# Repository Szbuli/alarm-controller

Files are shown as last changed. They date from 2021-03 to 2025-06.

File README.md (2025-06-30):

# Sensor Controller

## Main Features

- **15 configurable sensor inputs**  
- **Supported power supply:** 13.8 V nominal  
- **Home Assistant autodiscovery** via MQTT gateway
- **Input types supported:**  
  - Alarm sensors with multi-level signaling (e.g., open/tamper detection)  
  - Pulse counters (e.g., utility meters)

## Hardware

- **Microcontroller:** STM32F103R8T6  
- **Non-volatile memory:** MB85RC256V FRAM  
- **CAN Bus Transceiver:** SN65HVD230  
- **Electrical protection:**  
  - Overvoltage-protected inputs  
  - Overload protection circuitry  
- **Debug Interface:** Serial Wire Debug (SWD)

## Development Tools

- **PCB Design:** Autodesk EAGLE  
- **Firmware:** STM32CubeIDE (C via HAL / LL libraries)

## Setup
1. **Assign the device ID** via MQTT topic: `smarthome/alarm_controller/config`
2. **Configure sensor input types**
-- `1` → Alarm sensor
-- `3` → Pulse counter (normally open)
-- `4` → Pulse counter (normally closed)

## Sensor Connection & Security

To ensure reliable operation and tamper detection, each sensor input must be connected using a resistor for end-of-line (EOL) supervision.
The controller uses a voltage divider circuit to distinguish between different sensor states. The correct resistor value is essential for accurate detection:

- **Switch / Door Contact Sensors:**  
  Use a **40.2 kΩ** resistor in series with the sensor contact.  
- **Alarm Sensors:**  
  - **Normal (closed) signal:** ~40 kΩ total resistance  
  - **Alarm (open) signal:** ~140 kΩ total resistance

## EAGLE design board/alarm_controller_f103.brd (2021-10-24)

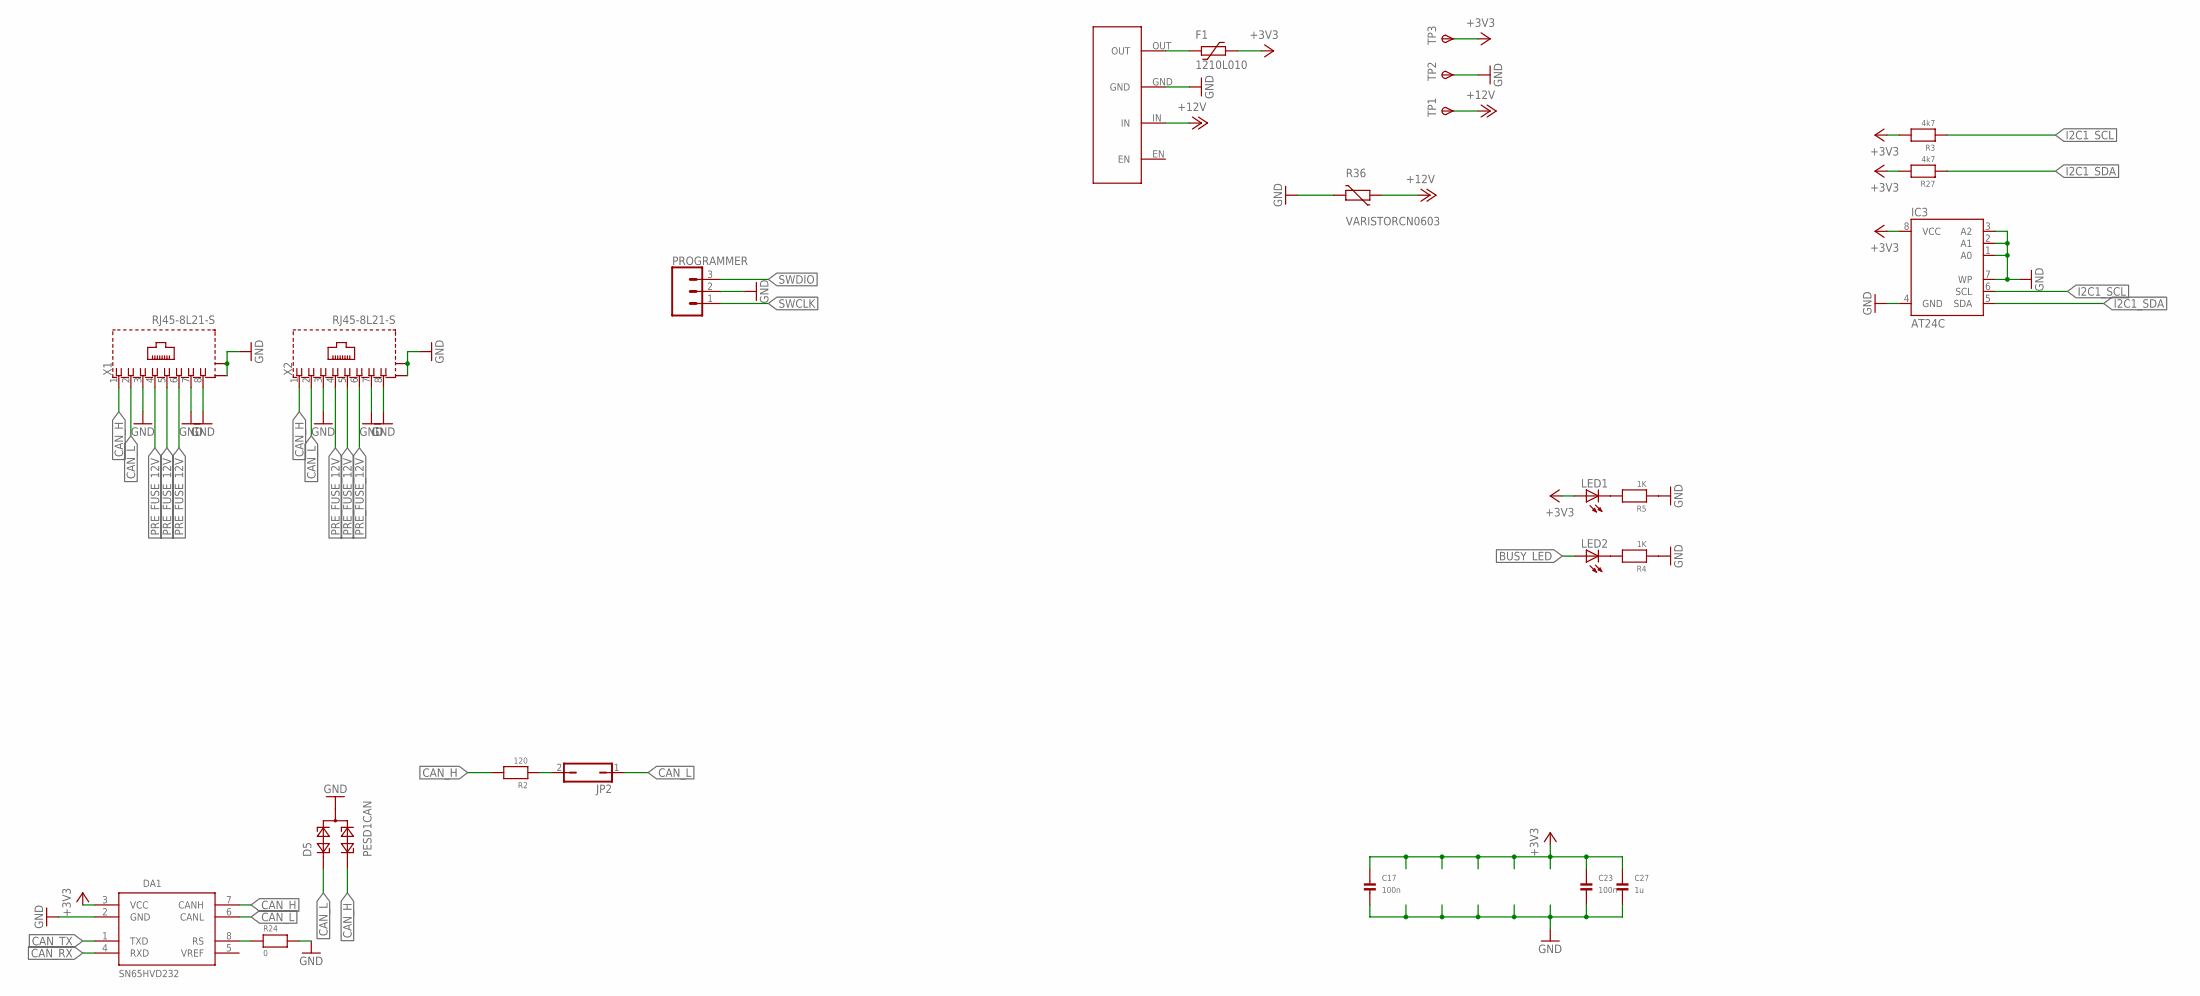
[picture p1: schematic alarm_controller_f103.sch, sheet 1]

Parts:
C17, C23: 100n; 0603
C27: 1u; 0603
D5: PESD1CAN; SOT23
DA1: SN65HVD232; SO08
F1: 1210L010; 1210L
IC3: AT24C; SOIC8
JP2: JP1Q; JP1
LED1, LED2: LEDCHIPLED_0805; CHIPLED_0805
PROGRAMMER: CONN_03LOCK; 1X03_LOCK
R2: 120; 0603
R3, R27: 4k7; 0603
R4, R5: 1K; 0603
R24: 0; 0603
R36: VARISTORCN0603; CT/CN0603
TP1, TP2, TP3: TPSTP20R; TP20R
U$4: HW-613
X1, X2: RJ45-8L21-S; RJ45-SHIELD1

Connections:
+3V3: C17.1, C23.1, C27.1, DA1.3 (VCC), F1.1, IC3.8 (VCC), LED1.A, R3.2, R27.2, TP3.TP; also elsewhere on the board
+12V: R36.1, TP1.TP, U$4.IN; also elsewhere on the board
BUSY_LED: LED2.A; also elsewhere on the board
CAN_H: D5.2, DA1.7 (CANH), R2.2, X1.1, X2.1
CAN_L: D5.1, DA1.6 (CANL), JP2.1, X1.2, X2.2
CAN_RX: DA1.4 (RXD); also elsewhere on the board
CAN_TX: DA1.1 (TXD); also elsewhere on the board
GND: C17.2, C23.2, C27.2, D5.3, DA1.2 (GND), IC3.1 (A0), IC3.2 (A1), IC3.3 (A2), IC3.4 (GND), IC3.7 (WP), PROGRAMMER.2, R4.1, R5.1, R24.2, R36.2, TP2.TP, U$4.GND, X1.3, X1.7, X1.8, X1.S1 (S), X1.S2 (S), X2.3, X2.7, X2.8, X2.S1 (S), X2.S2 (S); also elsewhere on the board
I2C1_SCL: IC3.6 (SCL), R3.1; also elsewhere on the board
I2C1_SDA: IC3.5 (SDA), R27.1; also elsewhere on the board
unnamed: F1.2, U$4.OUT
unnamed: LED1.C, R5.2
unnamed: LED2.C, R4.2
unnamed: JP2.2, R2.1
unnamed: DA1.8 (RS), R24.1
PRE_FUSE_12V: X1.4, X1.5, X1.6, X2.4, X2.5, X2.6; also elsewhere on the board
SWCLK: PROGRAMMER.1; also elsewhere on the board
SWDIO: PROGRAMMER.3; also elsewhere on the board

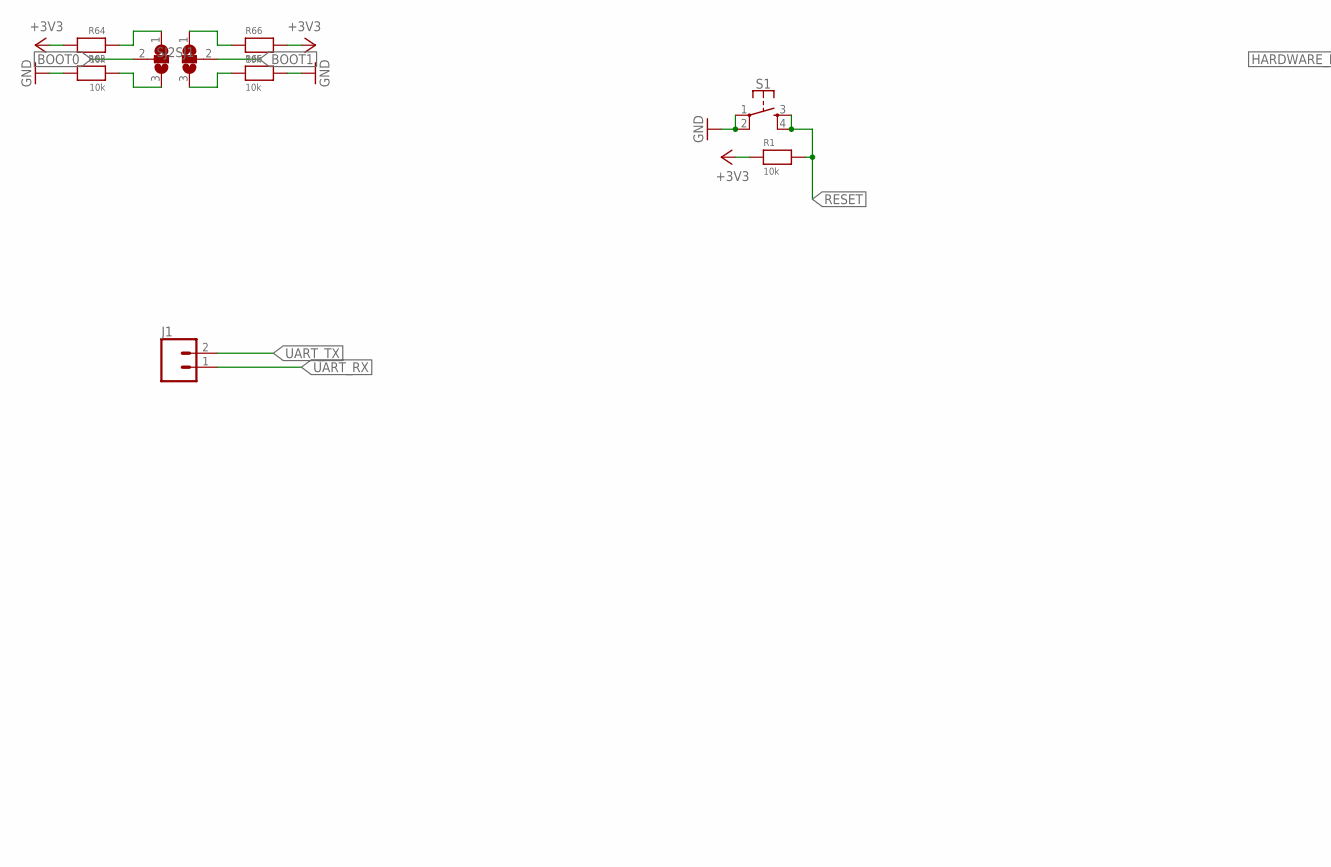
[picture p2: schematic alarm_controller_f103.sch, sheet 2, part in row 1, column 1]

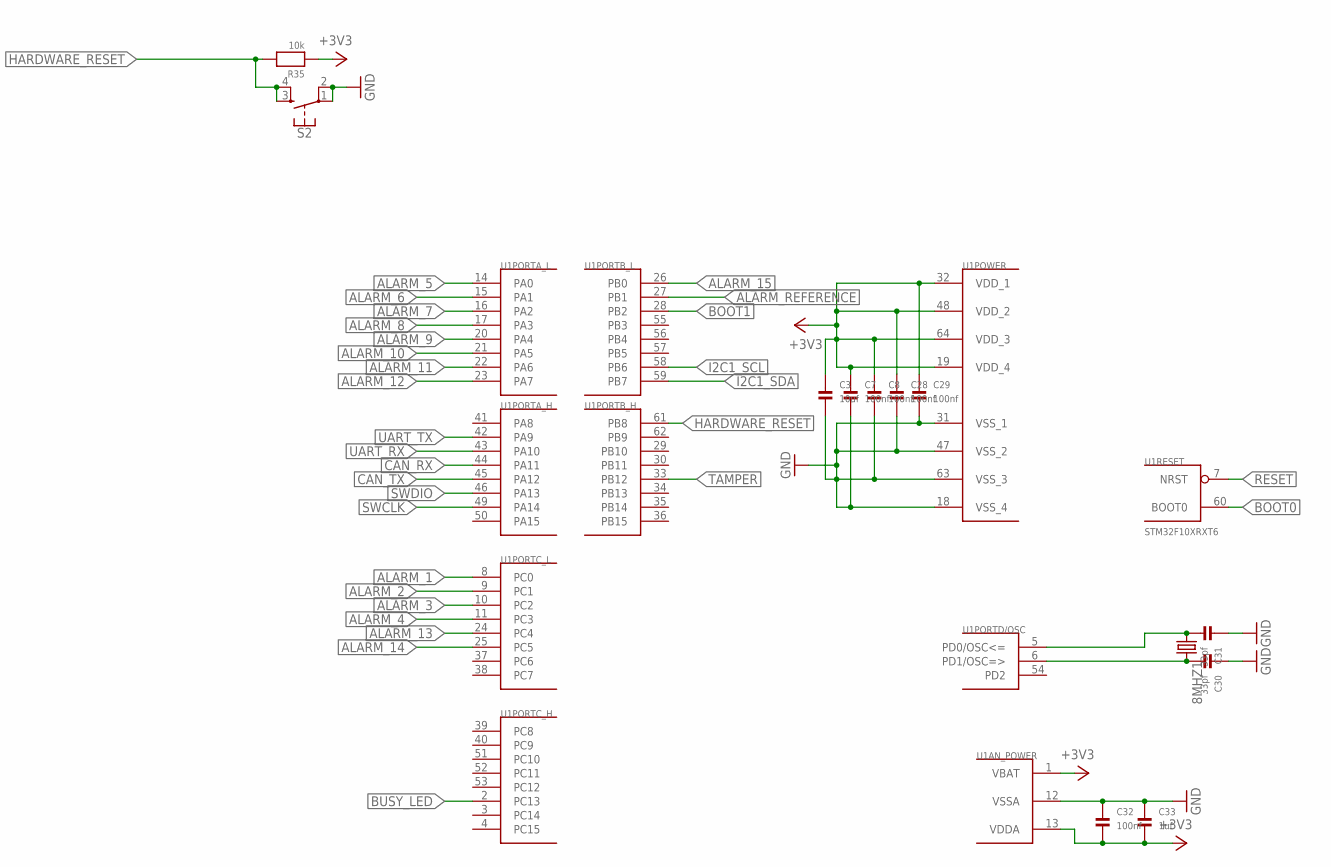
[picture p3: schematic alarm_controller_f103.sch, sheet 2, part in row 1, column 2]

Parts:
8MHZ1: CRYSTALHC49UP; HC49UP
C3: 10uf; 0805
C7, C8, C28, C29, C32: 100nf; 0603-MINI
C30, C31: 33pf; 0603
C33: 1uf; 0603-MINI
J1: CONN_02; 1X02
R1, R35, R63, R64, R65, R66: 10k; 0603
S1, S2: MOMENTARY-SWITCH-SPST-2-SMD-4.6X2.8MM; TACTILE_SWITCH_SMD_4.6X2.8MM
SJ1, SJ2: SJ2W; SJ_2
U1: STM32F10XRXT6; TQFP64

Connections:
+3V3: C3.1, C7.1, C8.1, C28.1, C29.1, C32.2, C33.2, R1.1, R35.1, R64.2, R66.2, U1.1 (VBAT), U1.13 (VDDA), U1.19 (VDD_4), U1.32 (VDD_1), U1.48 (VDD_2), U1.64 (VDD_3); also elsewhere on the board
ALARM_1: U1.8 (PC0); also elsewhere on the board
ALARM_2: U1.9 (PC1); also elsewhere on the board
ALARM_3: U1.10 (PC2); also elsewhere on the board
ALARM_4: U1.11 (PC3); also elsewhere on the board
ALARM_5: U1.14 (PA0); also elsewhere on the board
ALARM_6: U1.15 (PA1); also elsewhere on the board
ALARM_7: U1.16 (PA2); also elsewhere on the board
ALARM_8: U1.17 (PA3); also elsewhere on the board
ALARM_9: U1.20 (PA4); also elsewhere on the board
ALARM_10: U1.21 (PA5); also elsewhere on the board
ALARM_11: U1.22 (PA6); also elsewhere on the board
ALARM_12: U1.23 (PA7); also elsewhere on the board
ALARM_13: U1.24 (PC4); also elsewhere on the board
ALARM_14: U1.25 (PC5); also elsewhere on the board
ALARM_15: U1.26 (PB0); also elsewhere on the board
ALARM_REFERENCE: U1.27 (PB1); also elsewhere on the board
BOOT0: SJ1.2, U1.60 (BOOT0)
BOOT1: SJ2.2, U1.28 (PB2)
BUSY_LED: U1.2 (PC13); also elsewhere on the board
CAN_RX: U1.44 (PA11); also elsewhere on the board
CAN_TX: U1.45 (PA12); also elsewhere on the board
GND: C3.2, C7.2, C8.2, C28.2, C29.2, C30.1, C31.1, C32.1, C33.1, R63.2, R65.2, S1.1, S1.2, S2.1, S2.2, U1.12 (VSSA), U1.18 (VSS_4), U1.31 (VSS_1), U1.47 (VSS_2), U1.63 (VSS_3); also elsewhere on the board
HARDWARE_RESET: R35.2, S2.3, S2.4, U1.61 (PB8)
I2C1_SCL: U1.58 (PB6); also elsewhere on the board
I2C1_SDA: U1.59 (PB7); also elsewhere on the board
unnamed: R66.1, SJ2.1
unnamed: R64.1, SJ1.1
unnamed: R65.1, SJ2.3
unnamed: R63.1, SJ1.3
unnamed: 8MHZ1.2, C30.2, U1.6 (PD1/OSC=>)
unnamed: 8MHZ1.1, C31.2, U1.5 (PD0/OSC<=)
RESET: R1.2, S1.3, S1.4, U1.7 (NRST)
SWCLK: U1.49 (PA14); also elsewhere on the board
SWDIO: U1.46 (PA13); also elsewhere on the board
TAMPER: U1.33 (PB12); also elsewhere on the board
UART_RX: J1.1, U1.43 (PA10)
UART_TX: J1.2, U1.42 (PA9)

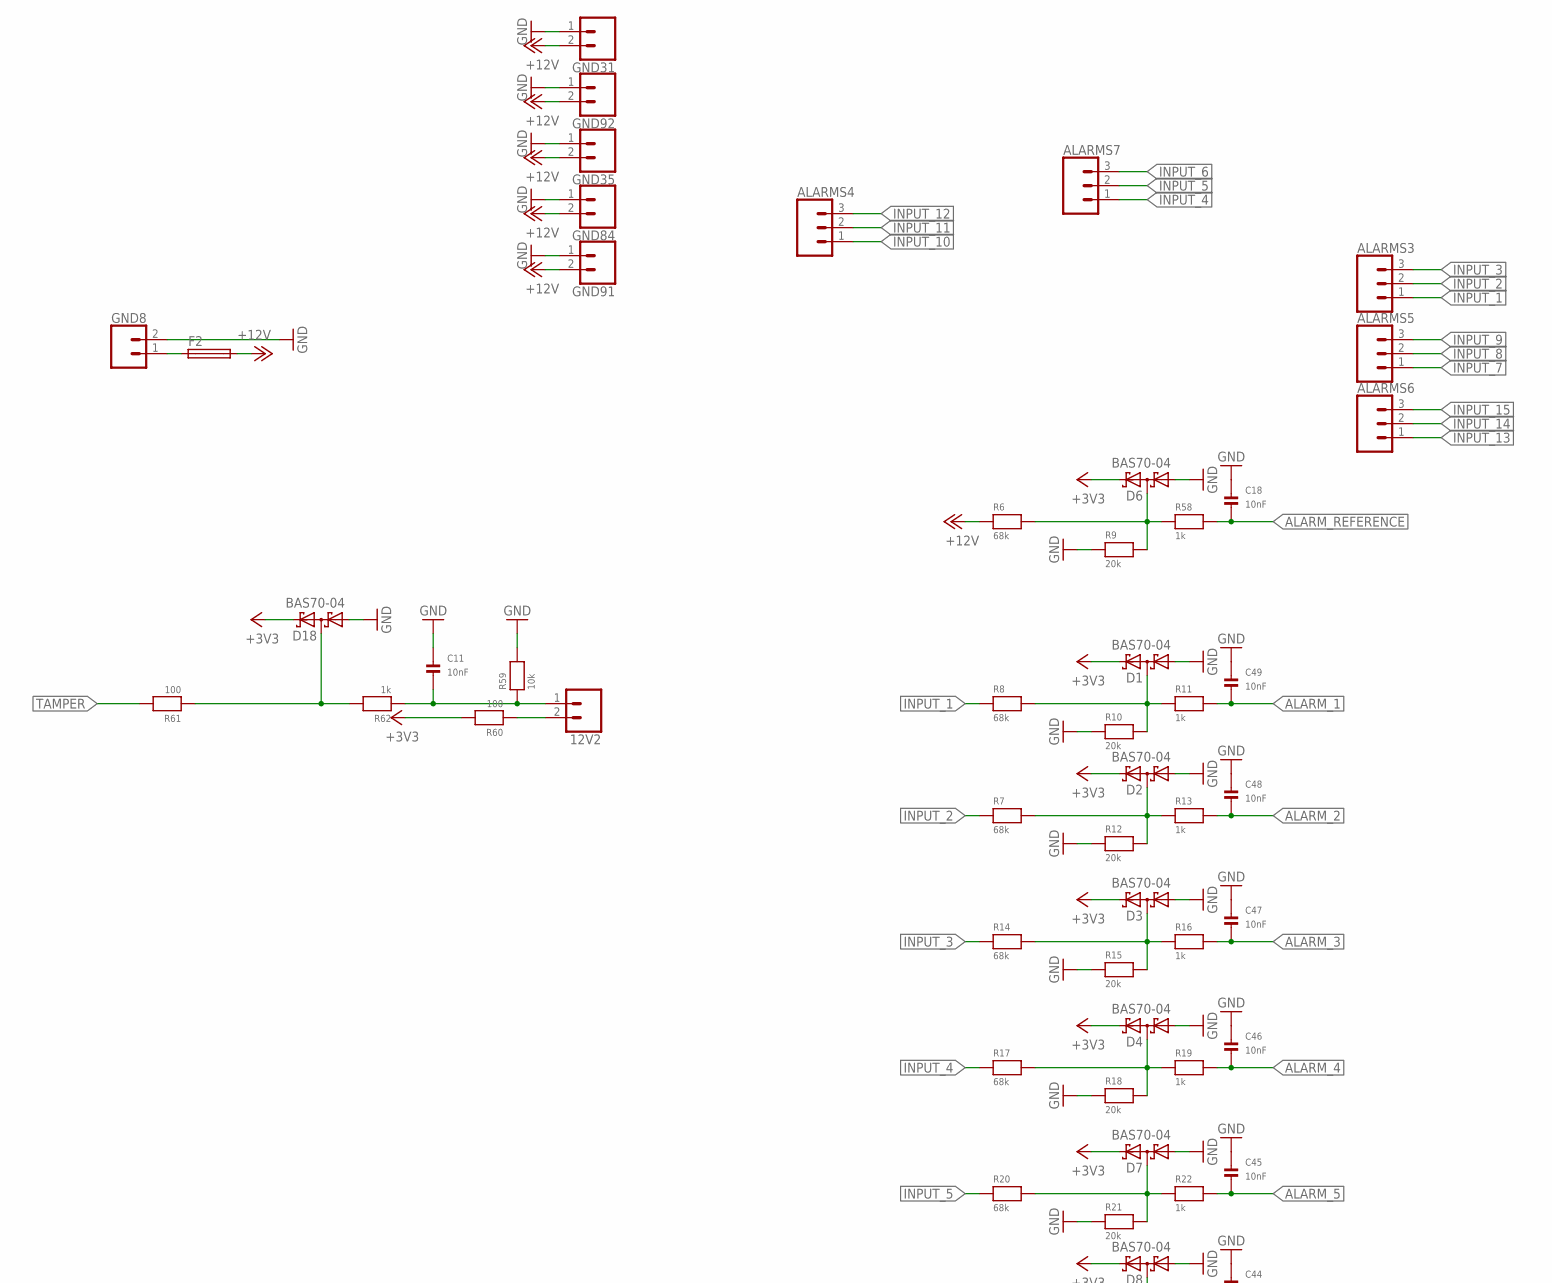
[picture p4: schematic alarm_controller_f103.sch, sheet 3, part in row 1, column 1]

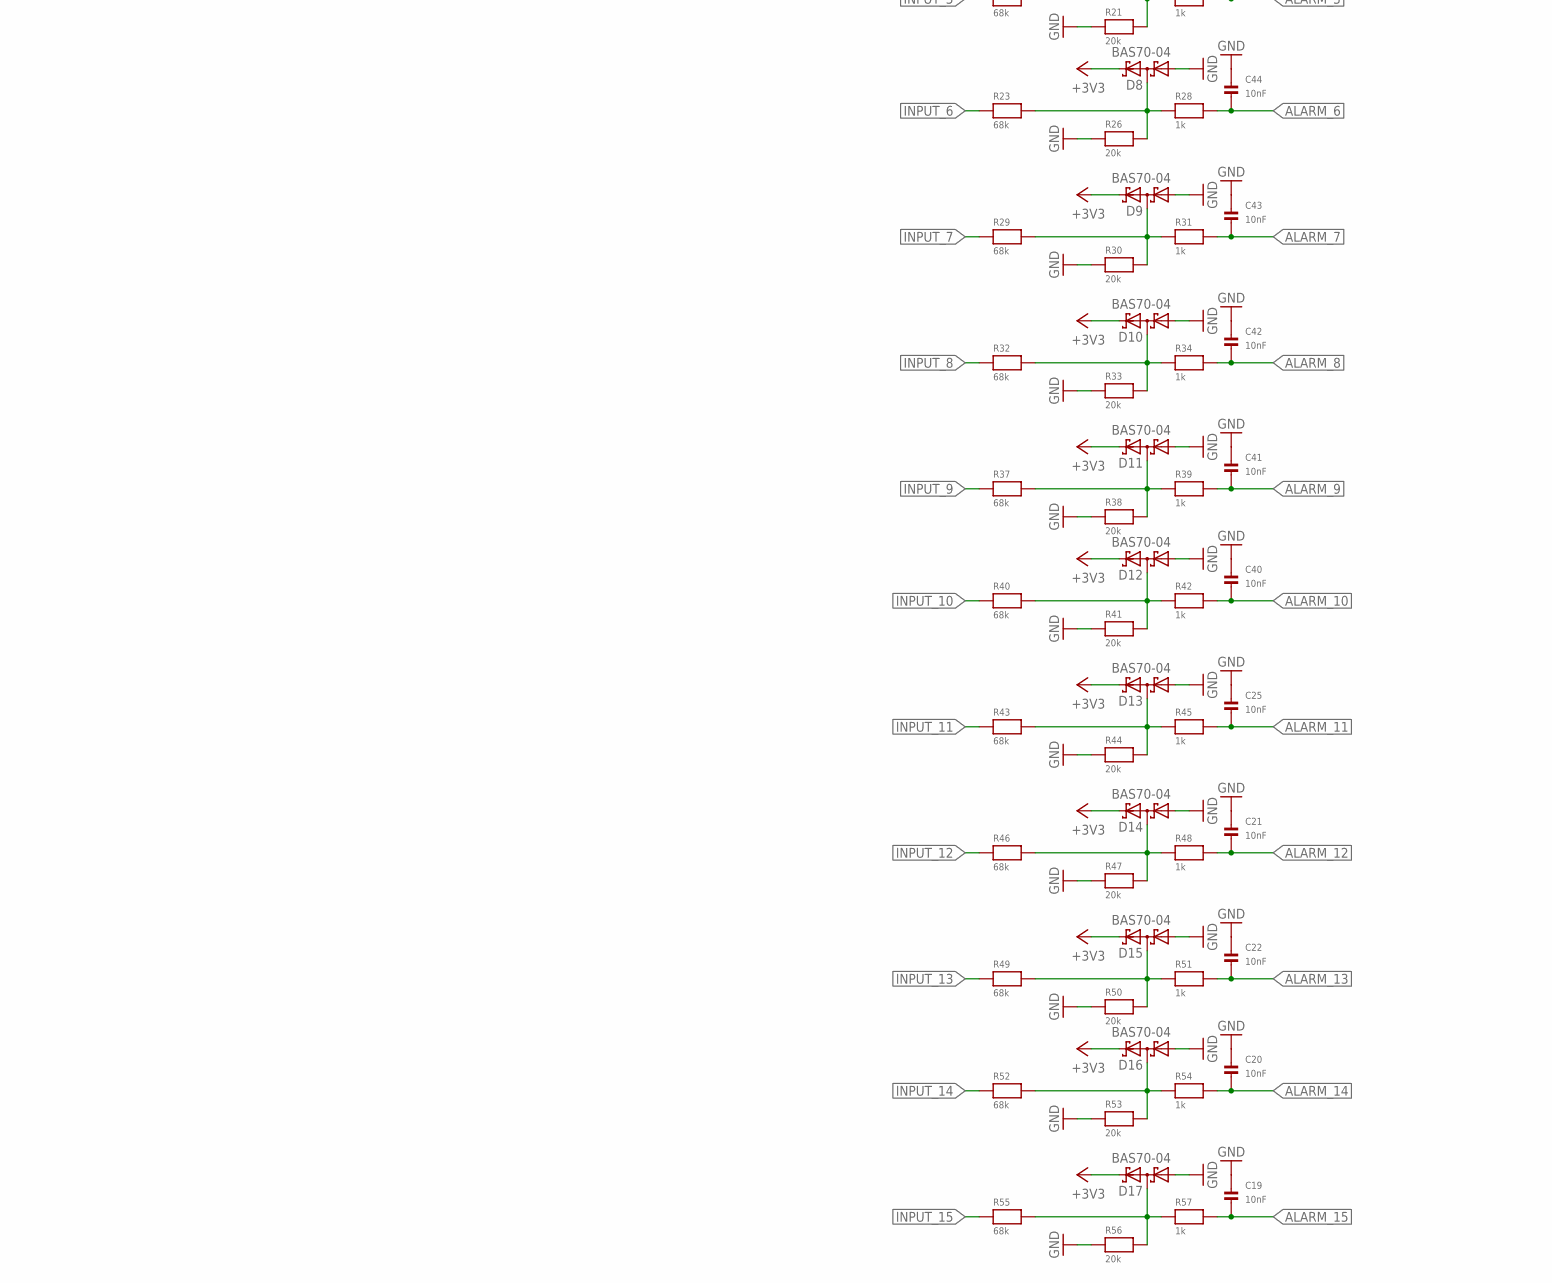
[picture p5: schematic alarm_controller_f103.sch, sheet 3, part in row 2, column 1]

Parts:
12V2: CONN_023.5MM; SCREWTERMINAL-3.5MM-2
ALARMS3, ALARMS4, ALARMS5, ALARMS6, ALARMS7: CONN_03SCREW_LOCK; SCREWTERMINAL-3.5MM-3_LOCK.007S
C11, C18, C19, C20, C21, C22, C25, C40, C41, C42, C43, C44, C45, C46, C47, C48, C49: 10nF; 0603
D1, D2, D3, D4, D6, D7, D8, D9, D10, D11, D12, D13, D14, D15, D16, D17, D18: BAS70-04; SOT23
F2: TE5
GND8: CONN_025MM; SCREWTERMINAL-5MM-2
GND31, GND35, GND84, GND91, GND92: CONN_023.5MM; SCREWTERMINAL-3.5MM-2
R6, R7, R8, R14, R17, R20, R23, R29, R32, R37, R40, R43, R46, R49, R52, R55: 68k; 0603
R9, R10, R12, R15, R18, R21, R26, R30, R33, R38, R41, R44, R47, R50, R53, R56: 20k; 0603
R11, R13, R16, R19, R22, R28, R31, R34, R39, R42, R45, R48, R51, R54, R57, R58, R62: 1k; 0603
R59: 10k; 0603
R60, R61: 100; 0603

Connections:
12V_REFERENCE1: D2.3 (C1A2), R7.2, R12.2, R13.1
12V_REFERENCE2: D3.3 (C1A2), R14.2, R15.2, R16.1
12V_REFERENCE3: D4.3 (C1A2), R17.2, R18.2, R19.1
12V_REFERENCE4: D7.3 (C1A2), R20.2, R21.2, R22.1
12V_REFERENCE5: D8.3 (C1A2), R23.2, R26.2, R28.1
12V_REFERENCE6: D9.3 (C1A2), R29.2, R30.2, R31.1
12V_REFERENCE7: D10.3 (C1A2), R32.2, R33.2, R34.1
12V_REFERENCE8: D11.3 (C1A2), R37.2, R38.2, R39.1
12V_REFERENCE9: D12.3 (C1A2), R40.2, R41.2, R42.1
12V_REFERENCE10: D13.3 (C1A2), R43.2, R44.2, R45.1
12V_REFERENCE11: D14.3 (C1A2), R46.2, R47.2, R48.1
12V_REFERENCE12: D15.3 (C1A2), R49.2, R50.2, R51.1
12V_REFERENCE13: D16.3 (C1A2), R52.2, R53.2, R54.1
12V_REFERENCE14: D17.3 (C1A2), R55.2, R56.2, R57.1
+3V3: D1.2 (C2), D2.2 (C2), D3.2 (C2), D4.2 (C2), D6.2 (C2), D7.2 (C2), D8.2 (C2), D9.2 (C2), D10.2 (C2), D11.2 (C2), D12.2 (C2), D13.2 (C2), D14.2 (C2), D15.2 (C2), D16.2 (C2), D17.2 (C2), D18.2 (C2), R60.2; also elsewhere on the board
+12V: F2.2, GND31.2, GND35.2, GND84.2, GND91.2, GND92.2, R6.1; also elsewhere on the board
A23: D6.3 (C1A2), R6.2, R9.2, R58.1
ALARM_1: C49.2, R11.2; also elsewhere on the board
ALARM_2: C48.2, R13.2; also elsewhere on the board
ALARM_3: C47.2, R16.2; also elsewhere on the board
ALARM_4: C46.2, R19.2; also elsewhere on the board
ALARM_5: C45.2, R22.2; also elsewhere on the board
ALARM_6: C44.2, R28.2; also elsewhere on the board
ALARM_7: C43.2, R31.2; also elsewhere on the board
ALARM_8: C42.2, R34.2; also elsewhere on the board
ALARM_9: C41.2, R39.2; also elsewhere on the board
ALARM_10: C40.2, R42.2; also elsewhere on the board
ALARM_11: C25.2, R45.2; also elsewhere on the board
ALARM_12: C21.2, R48.2; also elsewhere on the board
ALARM_13: C22.2, R51.2; also elsewhere on the board
ALARM_14: C20.2, R54.2; also elsewhere on the board
ALARM_15: C19.2, R57.2; also elsewhere on the board
ALARM_REFERENCE: C18.2, R58.2; also elsewhere on the board
ASD: D1.3 (C1A2), R8.2, R10.2, R11.1
ASDASD: D18.3 (C1A2), R61.1, R62.2
GND: C11.1, C18.1, C19.1, C20.1, C21.1, C22.1, C25.1, C40.1, C41.1, C42.1, C43.1, C44.1, C45.1, C46.1, C47.1, C48.1, C49.1, D1.1 (A1), D2.1 (A1), D3.1 (A1), D4.1 (A1), D6.1 (A1), D7.1 (A1), D8.1 (A1), D9.1 (A1), D10.1 (A1), D11.1 (A1), D12.1 (A1), D13.1 (A1), D14.1 (A1), D15.1 (A1), D16.1 (A1), D17.1 (A1), D18.1 (A1), GND8.2, GND31.1, GND35.1, GND84.1, GND91.1, GND92.1, R9.1, R10.1, R12.1, R15.1, R18.1, R21.1, R26.1, R30.1, R33.1, R38.1, R41.1, R44.1, R47.1, R50.1, R53.1, R56.1, R59.2; also elsewhere on the board
INPUT_1: ALARMS3.1, R8.1
INPUT_2: ALARMS3.2, R7.1
INPUT_3: ALARMS3.3, R14.1
INPUT_4: ALARMS7.1, R17.1
INPUT_5: ALARMS7.2, R20.1
INPUT_6: ALARMS7.3, R23.1
INPUT_7: ALARMS5.1, R29.1
INPUT_8: ALARMS5.2, R32.1
INPUT_9: ALARMS5.3, R37.1
INPUT_10: ALARMS4.1, R40.1
INPUT_11: ALARMS4.2, R43.1
INPUT_12: ALARMS4.3, R46.1
INPUT_13: ALARMS6.1, R49.1
INPUT_14: ALARMS6.2, R52.1
INPUT_15: ALARMS6.3, R55.1
unnamed: 12V2.2, R60.1
unnamed: 12V2.1, C11.2, R59.1, R62.1
PRE_FUSE_12V: F2.1, GND8.1; also elsewhere on the board
TAMPER: R61.2; also elsewhere on the board

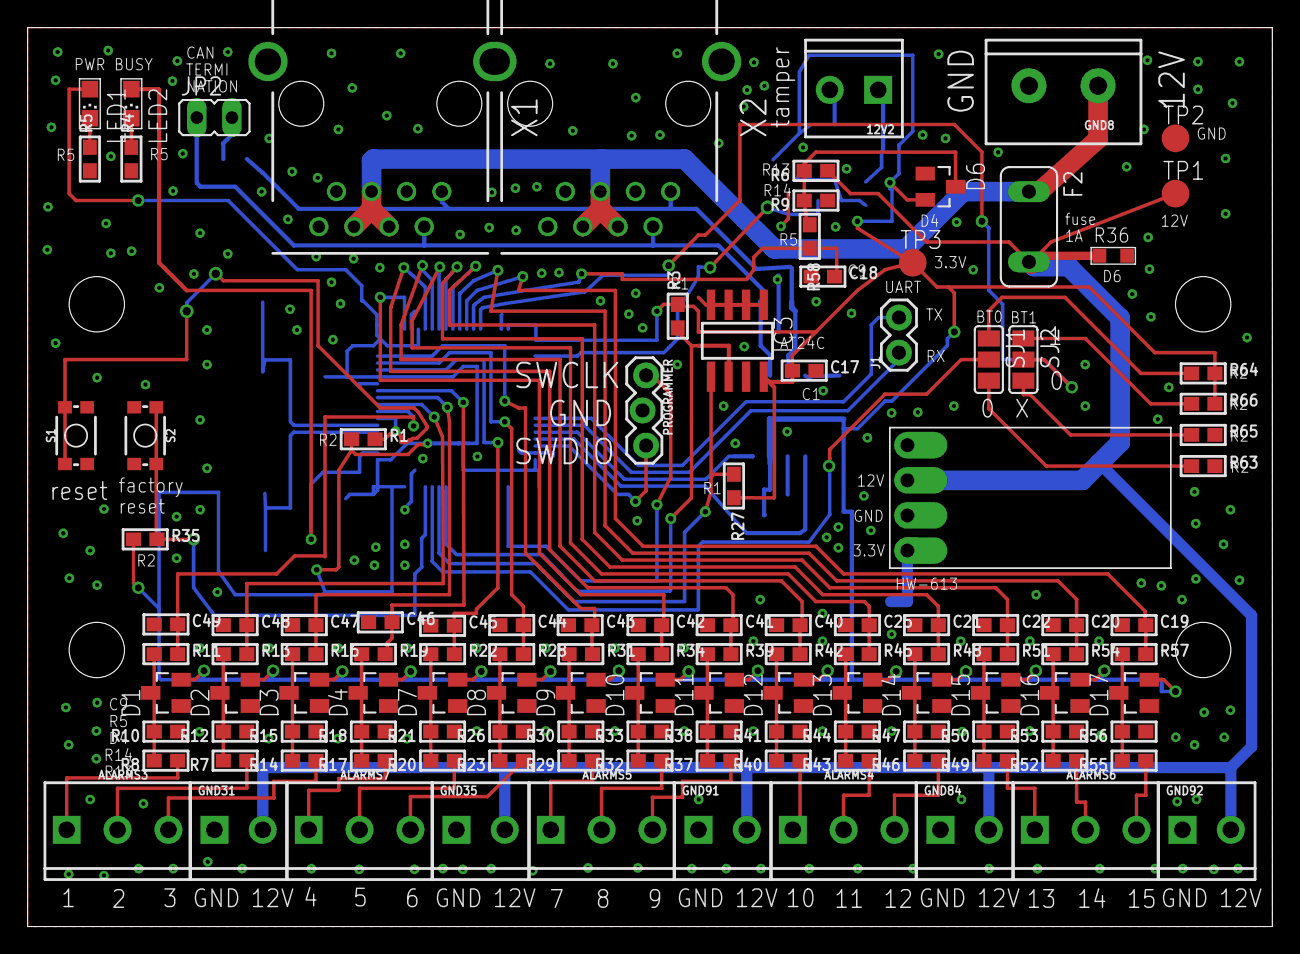
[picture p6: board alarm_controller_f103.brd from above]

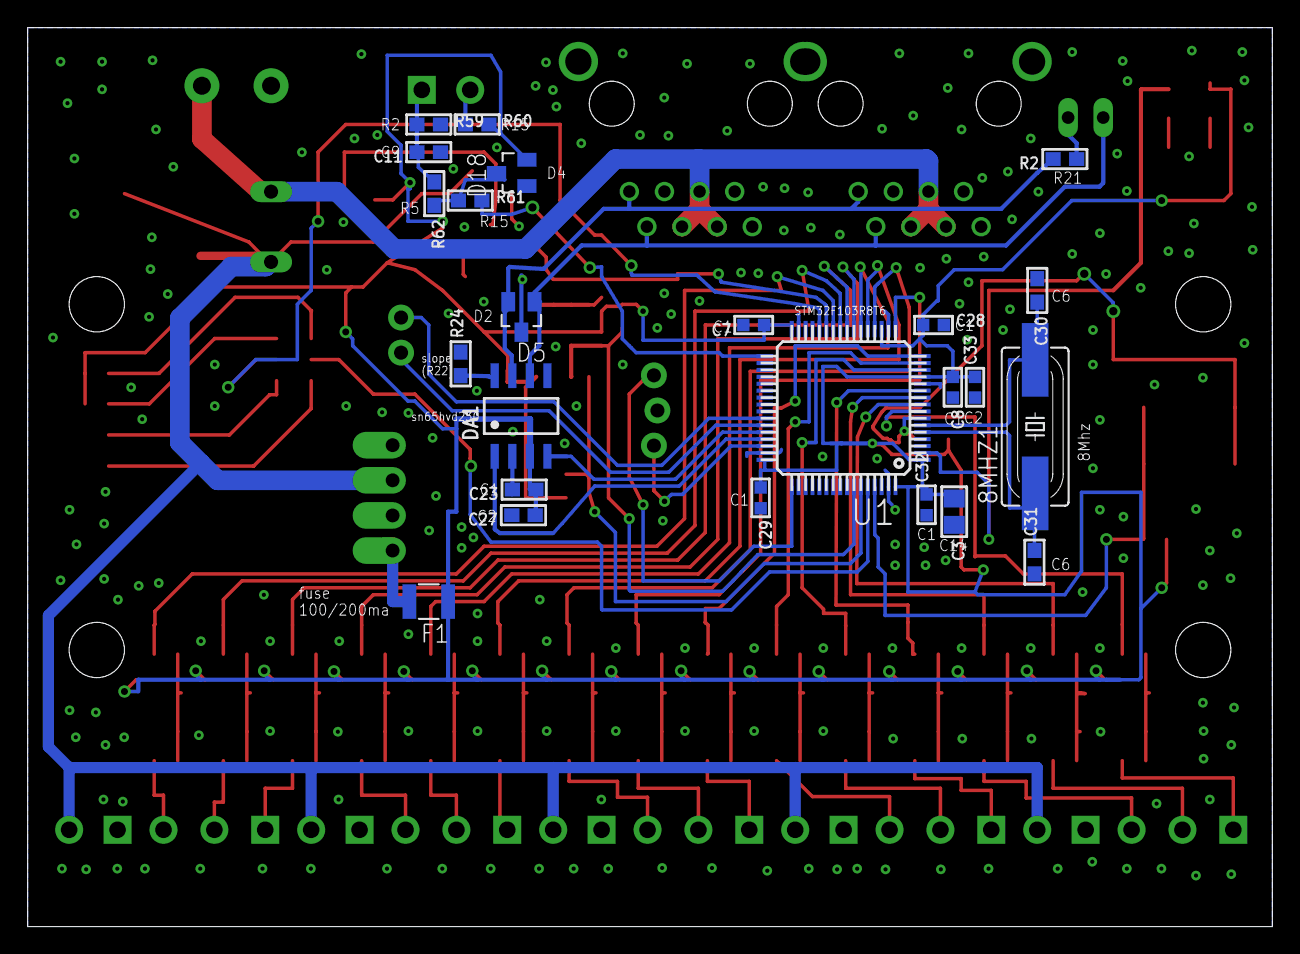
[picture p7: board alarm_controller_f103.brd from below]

Board: 2 copper layers, 90.0 x 65.0 mm, 147 parts (24 on the bottom side), 81 nets.

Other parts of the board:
U$5, U$6: C45-DIN-MOUNT-2-HOLE

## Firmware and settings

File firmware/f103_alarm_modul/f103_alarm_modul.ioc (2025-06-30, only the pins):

Mcu.UserName=STM32F103R8Tx
PA0-WKUP.GPIO_Label=ALARM_5
PA0-WKUP.Signal=ADCx_IN0
PA1.GPIO_Label=ALARM_6
PA1.Signal=ADCx_IN1
PA10.Signal=USART1_RX
PA11.Signal=CAN_RX
PA12.Signal=CAN_TX
PA13.Signal=SYS_JTMS-SWDIO
PA14.Signal=SYS_JTCK-SWCLK
PA2.GPIO_Label=ALARM_7
PA2.Signal=ADCx_IN2
PA3.GPIO_Label=ALARM_8
PA3.Signal=ADCx_IN3
PA4.GPIO_Label=ALARM_9
PA4.Signal=ADCx_IN4
PA5.GPIO_Label=ALARM_10
PA5.Signal=ADCx_IN5
PA6.GPIO_Label=ALARM_11
PA6.Signal=ADCx_IN6
PA7.GPIO_Label=ALARM_12
PA7.Signal=ADCx_IN7
PA9.Signal=USART1_TX
PB0.GPIO_Label=ALARM_15
PB0.Signal=ADCx_IN8
PB1.GPIO_Label=ALARM_12V_REFERENCE
PB1.Signal=ADCx_IN9
PB12.GPIO_Label=TAMPER
PB12.Signal=GPXTI12
PB2.GPIO_Label=BOOOOT2
PB2.Signal=GPIO_Input
PB6.Signal=I2C1_SCL
PB7.Signal=I2C1_SDA
PB8.GPIO_Label=FACTORY_RESET
PB8.Signal=GPIO_Input
PC0.GPIO_Label=ALARM_1
PC0.Signal=ADCx_IN10
PC1.GPIO_Label=ALARM_2
PC1.Signal=ADCx_IN11
PC13-TAMPER-RTC.GPIO_Label=BUSY_LED
PC13-TAMPER-RTC.Signal=GPIO_Output
PC2.GPIO_Label=ALARM_3
PC2.Signal=ADCx_IN12
PC3.GPIO_Label=ALARM_4
PC3.Signal=ADCx_IN13
PC4.GPIO_Label=ALARM_13
PC4.Signal=ADCx_IN14
PC5.GPIO_Label=ALARM_14
PC5.Signal=ADCx_IN15
PD0-OSC_IN.Signal=RCC_OSC_IN
PD1-OSC_OUT.Signal=RCC_OSC_OUT

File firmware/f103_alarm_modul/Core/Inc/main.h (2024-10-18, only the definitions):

#define BUSY_LED_Pin GPIO_PIN_13
#define BUSY_LED_GPIO_Port GPIOC
#define ALARM_1_Pin GPIO_PIN_0
#define ALARM_1_GPIO_Port GPIOC
#define ALARM_2_Pin GPIO_PIN_1
#define ALARM_2_GPIO_Port GPIOC
#define ALARM_3_Pin GPIO_PIN_2
#define ALARM_3_GPIO_Port GPIOC
#define ALARM_4_Pin GPIO_PIN_3
#define ALARM_4_GPIO_Port GPIOC
#define ALARM_5_Pin GPIO_PIN_0
#define ALARM_5_GPIO_Port GPIOA
#define ALARM_6_Pin GPIO_PIN_1
#define ALARM_6_GPIO_Port GPIOA
#define ALARM_7_Pin GPIO_PIN_2
#define ALARM_7_GPIO_Port GPIOA
#define ALARM_8_Pin GPIO_PIN_3
#define ALARM_8_GPIO_Port GPIOA
#define ALARM_9_Pin GPIO_PIN_4
#define ALARM_9_GPIO_Port GPIOA
#define ALARM_10_Pin GPIO_PIN_5
#define ALARM_10_GPIO_Port GPIOA
#define ALARM_11_Pin GPIO_PIN_6
#define ALARM_11_GPIO_Port GPIOA
#define ALARM_12_Pin GPIO_PIN_7
#define ALARM_12_GPIO_Port GPIOA
#define ALARM_13_Pin GPIO_PIN_4
#define ALARM_13_GPIO_Port GPIOC
#define ALARM_14_Pin GPIO_PIN_5
#define ALARM_14_GPIO_Port GPIOC
#define ALARM_15_Pin GPIO_PIN_0
#define ALARM_15_GPIO_Port GPIOB
#define ALARM_12V_REFERENCE_Pin GPIO_PIN_1
#define ALARM_12V_REFERENCE_GPIO_Port GPIOB
#define BOOOOT2_Pin GPIO_PIN_2
#define BOOOOT2_GPIO_Port GPIOB
#define TAMPER_Pin GPIO_PIN_12
#define TAMPER_GPIO_Port GPIOB
#define FACTORY_RESET_Pin GPIO_PIN_8
#define FACTORY_RESET_GPIO_Port GPIOB

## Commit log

2020-04-21 add board
    [alarm_controller.brd, alarm_controller.sch]
2020-05-01 init fw
    [f4_vet6_alarm_modul.cfg]
2020-05-02 change to premade power supply
    [alarm_controller.brd, alarm_controller.sch]
2020-05-03 change mounting to lib version
    [alarm_controller.brd]
2020-05-08 board - minor adjustments
    [alarm_controller.brd]
2020-05-08 update logo
    [alarm_controller.brd]
2020-05-08 add reset button
    [alarm_controller.brd, alarm_controller.sch]
2020-05-09 fix tamper
    [alarm_controller.brd, alarm_controller.sch]
2020-05-10 add support for hardware factory reset
    [f4_vet6_alarm_modul.ioc, home_config.c, home_config.h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]
2020-05-10 update uart logging
2020-06-11 power over can
    [alarm_controller.brd, alarm_controller.sch]
2020-06-11 fix hardware reset state
    [home_config.c]
2020-06-12 update board labels
    [alarm_controller.brd]
2020-06-29 add varistor
    [alarm_controller.brd, alarm_controller.sch]
2020-07-02 increase 12v and gnd connections
    [alarm_controller.brd, alarm_controller.sch]
2020-07-13 refresh eagle libs
    [alarm_controller.brd]
2020-07-18 jumpers for boot mode
    [alarm_controller.brd, alarm_controller.sch]
2020-07-18 fix labels
    [alarm_controller.brd]
2020-07-18 change to solderable boot jumper
    [alarm_controller.brd, alarm_controller.sch]
2020-11-23 change to microfit from rj45
    [alarm_controller.brd, alarm_controller.sch]
2020-11-24 change tamper output to regular 3.5mm screw terminal
    [alarm_controller.brd, alarm_controller.sch]
2020-12-02 redesign voltage divider circuits
    [alarm_controller.brd, alarm_controller.sch]
2020-12-03 update labels
    [alarm_controller.brd]
2020-12-03 set default boot mode label
    [alarm_controller.brd]
2021-01-03 clean up adc code
2021-01-10 fix board cfg
    [f4_vet6_alarm_modul.cfg]
2021-02-28 update some labels, fix can L and H mixup
    [alarm_controller.brd, alarm_controller.sch]
2021-02-28 add labels for ics
    [alarm_controller.brd]
2021-02-28 pwr led should be left
    [alarm_controller.brd]
2021-02-28 add default value for slope resistor
    [alarm_controller.brd]
2021-03-11 change back to rj45 (from microfit)
    [alarm_controller.brd, alarm_controller.sch]
2021-03-11 more distance between rj45 connectors
    [alarm_controller.brd]
2021-03-12 fix some labels
    [alarm_controller.brd]
2021-03-13 change to packages with place drawing
    [alarm_controller.brd, alarm_controller.sch]
2021-03-13 change deprecated labels
    [alarm_controller.brd]
2021-03-14 swap pwr input for correct orientation
    [alarm_controller.brd, alarm_controller.sch]
2021-10-24 move to f103 (#3)
    * basic ioc config
    * init firmware
    * add external crystal
    * change to new ic
    * fix some labels
    * fix ioc config
    * fix can bus speed
    * change task prios
    * ignore launch
    * heartbeat enabled by default
    * fine tune heartbeat
    * trigger heartbeat on first iteration
    [alarm_controller_f103.brd, alarm_controller_f103.sch, f103_alarm_modul.cfg]
2025-06-30 Feature/counter no pulse (#9)
    * add initial value for counter
    * increase can queue size
    * fix topic
    [can-ids.h, can_support.c, eeprom.c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]
2025-07-04 Bugfix/set count ha discovery (#10)
    * clear topic if not relevant
    * do not flood canbus
    * fix wrong topic
    * fix memory address
    [home_config.c]

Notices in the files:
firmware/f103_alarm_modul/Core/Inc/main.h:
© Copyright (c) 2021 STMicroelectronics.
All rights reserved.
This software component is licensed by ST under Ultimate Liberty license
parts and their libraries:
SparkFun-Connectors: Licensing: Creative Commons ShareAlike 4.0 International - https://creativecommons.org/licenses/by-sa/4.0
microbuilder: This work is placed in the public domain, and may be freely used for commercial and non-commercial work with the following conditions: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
